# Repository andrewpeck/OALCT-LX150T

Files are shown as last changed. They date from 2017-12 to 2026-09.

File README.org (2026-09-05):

#+TITLE: ALCT Spartan-6 LX150T Mezzanine
#+OPTIONS: toc:2 num:nil

This repository holds the Altium design for the ALCT Spartan-6 LX150T
mezzanine, produced for the CSC Phase 2 Upgrade. The documentation and
design files below are archived from the CMS TWiki topic
[[https://twiki.cern.ch/twiki/bin/view/CMS/ALCTCSCPhase2Upgrade][ALCTCSCPhase2Upgrade]].

Slides from the ALCT mezzanine Production Readiness Review, held on 8 June
2018 ([[https://indico.cern.ch/event/734723/][indico]]), provide additional information:
[[file:assets/20180608_alct_mezzanines_prr.pdf][20180608_alct_mezzanines_prr.pdf]]. The committee conclusions from the review
are available here: [[file:assets/ALCT_MEZ_Review_w_append.pdf][ALCT_MEZ_Review_w_append.pdf]].

Below, Version 1 refers to prototypes, Version 2 has been used for the
production runs.

* Overview

The ALCT Spartan-6 LX150T mezzanine is designed as a replacement mezzanine
for ALCT-672 motherboards, intended to be used in ME2/1, ME3/1, and ME4/1.
It also retains compatibility for ALCT-288 and ALCT-384 motherboards, but
its use is not expected there.

Relative to the 2012 Spartan-6 mezzanine, the new LX150T mezzanine adds two
3.2 Gbps (line rate) optical links providing 5.12 Gbps of user DAQ
bandwidth to the ODMB on a CERN radiation hard VTTx.

Due to the lack of LHC synchronous (40.08 MHz) reference clock on the board
because of a scarcity of QPLL ASICs, a commercial asynchronous 80.0 MHz
oscillator is used for the MGT reference clock.

#+CAPTION: ALCT Spartan-6 LX150T mezzanine, v2 (2019-01-23)
#+ATTR_HTML: :width 600


* Documentation

- pdf: [[file:assets/ALCT_spartan-6_lx150t_specification.pdf][ALCT_spartan-6_lx150t_specification.pdf]]
- word: [[file:assets/ALCT_spartan-6_lx150t_specification.docx][ALCT_spartan-6_lx150t_specification.docx]]

* Design Files
** Version 2

- v2 2019-01-23 Vendor Files (includes Gerber, ODB, NCdrill, BOM, etc):
  - [[file:assets/ALCT_MEZ_LX150T_v2_20190123_for_fabricator.zip][ALCT_MEZ_LX150T_v2_20190123_for_fabricator.zip]]
- v2 2019-01-23 Project files (includes Altium files):
  - [[file:assets/ALCT_MEZ_LX150T_PCB_PROJECT_20190123.zip][ALCT_MEZ_LX150T_PCB_PROJECT_20190123.zip]]
- v2 2019-01-23 schematics pdf:
  - [[file:assets/ALCT_MEZ_LX150T_Schematic_Color_2019-01-23_v2.pdf][ALCT_MEZ_LX150T_Schematic_Color_2019-01-23_v2.pdf]]
- v2 2019-01-23 layout PDF:
  - [[file:assets/ALCT_MEZ_LX150T_Layout_2019-01-23_v2.pdf][ALCT_MEZ_LX150T_Layout_2019-01-23_v2.pdf]]
- v2 2019-01-23 assembly drawing:
  - [[file:assets/ALCT_MEZ_LX150T_Assembly_Top_2019-01-23_v2.pdf][ALCT_MEZ_LX150T_Assembly_Top_2019-01-23_v2.pdf]]
  - [[file:assets/ALCT_MEZ_LX150T_Assembly_Bottom_2019-01-23_v2.pdf][ALCT_MEZ_LX150T_Assembly_Bottom_2019-01-23_v2.pdf]]
- v2 2019-01-23 Bill of Materials:
  - [[file:assets/ALCT_MEZ_LX150T_BOM_2018-10-31_v2.csv][ALCT_MEZ_LX150T_BOM_2018-10-31_v2.csv]]
- UCF File:
  - [[file:assets/LX150T_v1_alct672.ucf][LX150T_v1_alct672.ucf]] (unchanged from v1)
- ODMB modified firmware for PRBS link testing (temporary, non-official,
  for testing--- new ODMB firmware can substitute for this already. please
  contact [[https://twiki.cern.ch/twiki/bin/view/CMS/UCSB][UCSB]]).
  - project: [[file:assets/odmb_alct_test.tar.gz][odmb_alct_test.tar.gz]]
  - bit: [[file:assets/odmb_ucsb_v2.bit][odmb_ucsb_v2.bit]]
  - chipscope: [[file:assets/odmb_alct_test.cpj][odmb_alct_test.cpj]]

** Version 1

- v1 2017-12-06 prototype files (includes schematic, layout, BOM, gerbers):
  - [[file:assets/LX150T_v1_20171206.tar.gz][LX150T_v1_20171206.tar.gz]]
- v1 2017-12-06 prototype schematics PDF:
  - [[file:assets/ALCT_MEZ_LX150T_Schematic_Color_2017-12-06_v1.pdf][ALCT_MEZ_LX150T_Schematic_Color_2017-12-06_v1.pdf]]
- v1 2017-12-06 layout schematics PDF:
  - [[file:assets/ALCT_MEZ_LX150T_Layout_2017-12-06_v1.pdf][ALCT_MEZ_LX150T_Layout_2017-12-06_v1.pdf]]
- v1 2017-12-06 prototype assembly drawing:
  - [[file:assets/ALCT_MEZ_LX150T_Assembly_Bottom_2017-12-06_v1.pdf][ALCT_MEZ_LX150T_Assembly_Bottom_2017-12-06_v1.pdf]]
  - [[file:assets/ALCT_MEZ_LX150T_Assembly_Top_2017-12-06_v1.pdf][ALCT_MEZ_LX150T_Assembly_Top_2017-12-06_v1.pdf]]
- UCF File:
  - [[file:assets/LX150T_v1_alct672.ucf][LX150T_v1_alct672.ucf]]

* Radiation testing

For 3000 fb^-1 of HL-LHC running, the maximum expected TID for the
ALCT-LX150T is 3 kRad.

All parts used on the ALCT-LX150T ([[file:assets/Bill_of_Materials-ALCT_MEZ_LX150T.csv][BOM]]) have been tested with TIDs equal or
greater to 30 kRad. Slides 62-64 of the ALCT talk in the ESR
([[file:assets/18-07-02_Andrew_Peck_-_alct_mezzanines_esr_v6.pdf][pdf]]) lay out the tests for each part:

- Most parts were also used in the ALCT-S6 board, installed during LS1.
  These parts were successfully tested in June 2012 at the UC Davis
  cyclotron to 30 kRad ([[file:assets/12-07-20_Jay_Hauser_-_ALCT_mezz_for_ME11-2.pdf][pdf]])
- The new XC6SLX150T FPGA is also used in the MPC and was successfully
  tested in April 2013 at the UC Davis cyclotron to 100 kRad
  ([[file:assets/13-04-01_Davis_LX150T_MPC_tests.pdf][pdf]]). MGTs were successfully tested in Jun 2018 to 15 kRad
  ([[file:assets/18-07-25_TAMU_test_Feb_2017.pdf][pdf]])
- The new oscillators (ASV-33.000MHZ-EJ-T and SG3225VAN 80.000000M-KEGA3)
  were tested in April 2018 at the Texas A&M reactor to 30 kRad
  ([[file:assets/18-07-21_TAMU_test_Mar_2018.pdf][pdf]])
- The VTTx is a radiation-hard transceiver qualified by CERN
  ([[file:assets/VTRx_Spec_v2.2.pdf][pdf]])

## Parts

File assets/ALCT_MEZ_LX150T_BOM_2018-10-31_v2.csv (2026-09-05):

Comment | Description | Designator | Footprint | LibRef | Manufacturer | Manufacturer Part Number | Quantity | Supplier 1 | Supplier Part Number 1
4.7uF | CAP CER 4.7UF 35V X5R 0603 | C1, C2, C9, C10, C88, C89, C107, C120, C121, C122, C123, C124, C125, C126, C127, C128, C129, C130, C131, C132, C134, C135, C136, C137, C138, C139, C140, C141, C142, C143, C144, C301, C311, C321, C331, C341, C351, C361, C362, C363, C364, C371, C372, C373, C374 | MC_S6/SM/C_0603_IPC | GRM188R6YA475KE15D | Murata | GRM188R6YA475KE15D | 45 | Digikey | 490-7205-1-ND
10uF | CAP CER 10UF 25V X5R 0805 | C3, C4, C6, C7, C11, C12, C14, C15, C17, C18, C29, C54, C58, C60, C65, C69, C71, C82, C90, C99, C100, C103, C110, C113, C146, C302, C312, C322, C332, C342, C365, C375 | MC_S6/SM/C_0805_IPC | GRM21BR61E106KA73L | Murata Electronics North America | GRM21BR61E106KA73L | 32 | Digi-Key | 490-5523-1-ND
0.01uF | CAP CER 10nF 16V X7R 0402 | C5, C8, C13, C16, C19, C26, C27, C84, C85, C106, C116, C133, C145, C148 | MC_S6/SM/C_0402_IPC | C0402C103K4RACTU | KEMET | C0402C103K4RACTU | 14 | Digi-Key | 399-1038-1-ND
0.47uF | CAP CER 0.47UF 10V X5R 0402 | C20, C21, C22, C23, C24, C25, C33, C40, C41, C42, C43, C44, C45, C46, C47, C78, C83, C101, C111, C119, C147, C201, C202, C203, C204, C205, C211, C212, C213, C214, C215, C221, C222, C223, C224, C225, C231, C232, C233, C234, C235, C241, C242, C243, C244, C251, C252, C253, C254, C261, C262, C263, C264, C265, C266, C267, C268, C271, C272, C273, C274, C275, C276 | MC_S6/SM/C_0402_IPC | GRM155R61A474KE15J | Murata Electronics North America | GRM155R61A474KE15J | 63 | Digi-Key | 490-6305-1-ND
0.1uF | CAP CER 0.1UF 16V X7R 0402 | C28, C30, C31, C32, C50, C51, C52, C53, C55, C56, C57, C59, C61, C62, C63, C64, C66, C67, C68, C70, C72, C73, C74, C75, C76, C77, C105, C109, C115 | MC_S6/SM/C_0402_IPC | C0402C104K4RACTU | KEMET | C0402C104K4RACTU | 29 | Digi-Key | 399-3521-1-ND
0.01uF | CAP CER 10000PF 50V NP0 0603 | C80, C81, C97, C98 | MC_S6/SM/C_0603_IPC | C0603C103J3GACTU | KEMET | C0603C103J3GACTU | 4 | Digi-Key | 399-7838-1-ND
100uF | CAP CER 100UF 10V X5R 1210 | C86, C87, C102, C112, C401, C411, C421, C431, C441, C451, C461, C462, C471, C472 | MC_S6/SM/C_1210_IPC | LMK325BJ107MM-T | Taiyo Yuden | LMK325BJ107MM-T | 14 | Digi-Key | 587-1965-1-ND
0.22uF | CAP CER 0.22UF 15V X7R 0402 | C91, C92, C93, C94, C95, C96 | MC_S6/SM/C_0402_IPC | GRM155R71C224KA12D | Murata Electronics North America | GRM155R71C224KA12D | 6 | Digi-Key | 490-5418-1-ND
0.47uF | CAP CER 0.47UF 25V X7R 0603 | C104, C108, C114, C117, C118 | MC_S6/SM/C_0603_IPC | GRM188R71E474KA12D | Murata | GRM188R71E474KA12D | 5 | Digikey | 490-3291-1-ND
220uF | CAP TANT 220UF 16V 10% 2917 | CT1, CT2, CT3, CT4, CT5, CT6, CT7, CT8, CT9, CT10, CT11, CT12, CT13 | MC_S6/SM/CT_2917_D | T491D227K016AT | KEMET | T491D227K016AT | 13 | Digi-Key | 399-10429-1-ND
LTST-C193TBKT-5A | LED BLUE CLEAR 0603 SMD | D1 | MC_S6/SM/LED_0603 | LTST-C193TBKT-5A | Lite-On Inc. | LTST-C193TBKT-5A | 1 | Digi-Key | 160-1827-1-ND
LTST-C193KGKT-5A | LED GREEN CLEAR 0603 SMD | D2 | MC_S6/SM/LED_0603 | LTST-C193KGKT-5A | Lite-On Inc. | LTST-C193KGKT-5A | 1 | Digi-Key | 160-1828-1-ND
LTST-C193KRKT-5A | LED RED CLEAR 0603 SMD | D40, D41 | MC_S6/SM/LED_0603 | LTST-C193KRKT-5A | Lite-On Inc. | LTST-C193KRKT-5A | 2 | Digi-Key | 160-1830-1-ND
VTTX | CONN FP+ CAGE 30AU SMD | J1 | MC_S6/SM/TE-1888247-1 | VTTX | TE Connectivity AMP Connectors | 1888247-1 | 1 | Digi-Key | A97943CT-ND
1uH | IND, Air Core, 1uH, 880mA, TH | L3, L4 | MC_S6/TH/DELEVAN1537 | 1537-12K | API Delevan Inc. | 1537-12K | 2 | Digi-Key | 1134-1088-1-ND
CERN VTTX | Versatile Twin Transmitter Module | PCBM1 | PCBM_CERN_VTTX V2.1 |  | CERN | VTTX-V2.1 | 1
1.2k | RES SMD 1.2K OHM 0.1% 1/16W 0402 | R1, R15 | MC_S6/SM/R_0402_IPC | ERA-2AEB122X | Panasonic Electronic Components | ERA-2AEB122X | 2 | Digi-Key | P1.2KDCCT-ND
4.7k | RES SMD 4.7K OHM 1% 1/10W 0603 | R2, R5, R8, R11, R16, R40, R43, R44, R55, R81, R82, R83, R101, R103, R104, R105, R106, R108 | MC_S6/SM/R_0603_IPC | CR0603-FX-4701ELF | Bourns Inc. | CR0603-FX-4701ELF | 18 | Digi-Key | CR0603-FX-4701ELFCT-ND
300R | RES SMD 300 OHM 0.1% 1/16W 0402 | R3, R17 | MC_S6/SM/R_0402_IPC | ERA-2AEB301X | Panasonic Electronic Components | ERA-2AEB301X | 2 | Digi-Key | P300DCCT-ND
5.1k | RES SMD 5.1K OHM 0.1% 1/16W 0402 | R4, R20, R21, R22, R23, R26, R27, R28 | MC_S6/SM/R_0402_IPC | ERA-2AEB512X | Panasonic Electronic Components | ERA-2AEB512X | 8 | Digi-Key | P5.1KDCCT-ND
1.96k | RES SMD 1.96K OHM 0.1% 1/16W 0402 | R6 | MC_S6/SM/R_0402_IPC | ERA-2AEB1961X | Panasonic Electronic Components | ERA-2AEB1961X | 1 | Digi-Key | P1.96KDCCT-ND
1.8k | RES SMD 1.8k OHM 0.1% 1/16W 0402 | R7, R10 | MC_S6/SM/R_0402_IPC | ERA-2AEB182X | Panasonic Electronic Components | ERA-2AEB182X | 2 | Digi-Key | P1.8KDCCT-ND
1.3k | RES SMD 1.3k OHM 0.1% 1/16W 0402 | R9, R12 | MC_S6/SM/R_0402_IPC | ERA-2AEB132X | Panasonic Electronic Components | ERA-2AEB132X | 2 | Digi-Key | P1.3KDCCT-ND
110R | RES SMD 110 OHM 1% 1/10W 0402 | R13, R14, R56, R57 | MC_S6/SM/R_0402_IPC | ERJ-2RKF1100X | Panasonic Electronic Components | ERJ-2RKF1100X | 4 | Digi-Key | P110LCT-ND
768R | RES SMD 768 OHM 5.0% 1/10W 0402 | R24, R25 | MC_S6/SM/R_0402_IPC | ERJ-2RKF7680X | Panasonic Electronic Components | ERJ-2RKF7680X | 2 | Digi-Key | P768LCT-ND
10M | RES SMD 10M OHM 5% 1/10W 0402 | R41, R48, R49, R54 | MC_S6/SM/C_0402_IPC | ERJ-2GEJ106X | Panasonic Electronic Components | ERJ-2GEJ106X | 4 | Digi-Key | P10MJCT-ND
330R | RES SMD 330 OHM 1% 1/10W 0603 | R42, R107 | MC_S6/SM/R_0603_IPC | CR0603-FX-3300ELF | Bourns Inc. | CR0603-FX-3300ELF | 2 | Digi-Key | CR0603-FX-3300ELFCT-ND
510R | RES SMD 510 OHM 1% 1/10W 0603 | R45, R58, R59 | MC_S6/SM/R_0603_IPC | CR0603-FX-5100ELF | Bourns Inc. | CR0603-FX-5100ELF | 3 | Digi-Key | CR0603-FX-5100ELFDKR-ND
28R | RES SMD 28 OHM 1% 1/10W 0603 | R46 | MC_S6/SM/R_0603_IPC | ERJ-3EKF28R0V | Panasonic Electronic Components | ERJ-3EKF28R0V | 1 | Digi-Key | P28.0HCT-ND
0.0R | RES SMD 0.0OHM JUMPER 1/10W 0402 | R50, R51, R52, R53 | MC_S6/SM/R_0402_IPC | ERJ-2GE0R00X | Panasonic Electronic Components | ERJ-2GE0R00X | 4 | Digi-Key | P0.0JCT-ND
49.9R | RES SMD 49.9 OHM 0.1% 1/8W 0805 | R80 | MC_S6/SM/R_0805_IPC | ERA-6AEB49R9V | Panasonic Electronic Components | ERA-6AEB49R9V | 1 | Digi-Key | P49.9DACT-ND
187R | RES SMD 187 OHM 1% 1/10W 0603 | R100, R102 | MC_S6/SM/R_0603_IPC | ERJ-3EKF1870V | Panasonic Electronic Components | ERJ-3EKF1870V | 2 | Digi-Key | P187HCT-ND
XC6SLX150T-3FGG900C | Spartan-6 LXT 1.2V FPGA, 540 User I/Os, 900-Ball Chip-Scale BGA (1.0mm Pitch), Speed Grade 3, Commercial Grade, Pb-Free | U1 | MC_S6/BGA/FGG900 | XC6SLX150T-3FGG900C | Xilinx Inc. | XC6SLX150T-3FGG900C | 1 | Digi-Key | XC6SLX150T-3FGG900C-ND
XCF32PVOG48C | IC PROM SRL/PAR 1.8V 32M 48TSOP | U2 | MC_S6/SM/VOG48 | XCF32PVOG48C | Xilinx Inc. | XCF32PVOG48C | 1 | Digi-Key | 122-1458-ND
XCF08PVOG48C | IC PROM SRL/PAR 1.8V 08M 48TSOP | U3 | MC_S6/SM/VOG48 | XCF08PVOG48C | Xilinx Inc. | XCF08PVOG48C | 1 | Digi-Key | 122-1454-ND
74LVC161PW,118 | IC SYNC 4BIT BIN COUNTER 16TSSOP | U4 | MC_S6/SM/TSSOP16 | 74LVC161PW | NXP USA Inc. | 74LVC161PW,118 | 1 | Digi-Key | 568-7667-1-ND
DS1233AZ-10+ | IC POR 2.88V 10% SOT223 | U5 | MC_S6/SM/SOT223_1243 | DS1233AZ-10+ | Maxim Integrated | DS1233AZ-10+T&R | 1 | Digi-Key | DS1233AZ-10+CT-ND
SN74LVC1G07-EP | IC BUFF/DVR NON-INVERT Open Drain SC70-5 | U6, U100 | MC_S6/SM/SOT_SC70_DCK5 | SN74LVC1G07-EP | Texas Instruments | SN74LVC1G07MDCKREP | 2 | Digi-Key | 296-22343-1-ND
SN74LVC1T45DCKR | IC BUS TRANSCVR TRI-ST SC70-6 | U7, U8, U9, U10 | MC_S6/SM/SOT_SC70_DCK6 | SN74LVC1T45-EP-ALCT_1 | Texas Instruments | SN74LVC1T45DCKR | 4 | Digi-Key | 296-16844-1-ND
DS2401Z | IC Digital Serial Number | U11 | MC_S6/SM/SOT223_1243 | DS2401_sot223 | Maxim Integrated | DS2401Z+T&R | 1 | Digi-Key | DS2401Z+T&RCT-ND
MIC69502WR | IC REG LDO ADJ 5A SPAK-7 | U12, U13, U14, U20, U21 | MC_S6/SM/SPAK7 | MIC69502WR | Microchip Technology | MIC69502WR | 5 | Digi-Key | 576-1613-ND
TLV2543CDB | IC SERIAL OUT A/D 11-CH 20-SSOP | U15 | MC_S6/SM/ADC_DB20 | TLV2543CDB | Texas Instruments | TLV2543CDBR | 1 | Digi-Key | 296-10643-1-ND
LT1634ACS8-2.5 | IC VREF SHUNT 2.5V 8SOIC | U16 | MC_S6/SM/LT1634_SOIC8 | LT1634_2.5V | Linear Technology | LT1634ACS8-2.5#PBF | 1 | Digi-Key | LT1634ACS8-2.5#PBF-ND
SN74LVC1G34 | IC BUFFER NON-INVERT SOT5 | U17 | MC_S6/SM/SOT_553_DRL5 | SN74LVC1G34DRLR | Texas Instruments | SN74LVC1G34DRLR | 1 | Digi-Key | 296-18017-1-ND
TMP36GRTZ | SENSOR TEMP ANLG VOLT SOT-23-5 | U18, U19 | MC_S6/SM/SOT23_RJ5 | TMP36GRTZ | Analog Devices | TMP36GRTZ-REEL7 | 2 | Digi-Key | TMP36GRTZ-REEL7CT-ND
74AUP1G04GW | IC INVERTER LP 5TSSOP | U40 | SOT353-1 | 74AUP1G04GW | Nexperia USA Inc. | 74AUP1G04GW,125 | 1 | Digi-Key | 1727-3176-1-ND
DS90LV047ATMTCX/NOPB | IC LINE DVR 3V QUAD DIFF 16TSSOP | U80 | MC_S6/SM/TSSOP16 | DS90LV047ATMTCX | TI National Semiconductor | DS90LV047ATMTCX/NOPB | 1 | Digi-Key | DS90LV047ATMTCX/NOPBDKR-ND
74LVC2T45DC,125 | IC TRNSLTR BIDIRECTIONAL 8VSSOP | U101 | VSSOP8 SOT765-1 | 74LVC2T45DC,125 | Nexperia USA Inc. | 74LVC2T45DC,125 | 1 | Digi-Key | 1727-4578-6-ND
SG3225VAN 80.000000M-KEGA3 | OSC 80.0000MHZ LVDS SMD | X1 | MC_S6/SM/XTAL-LVDS-3.2-2.5 | SG3225VAN 80.000000M-KEGA3 | EPSON | SG3225VAN 80.000000M-KEGA3 | 1 | Digi-Key | SER3935CT-ND
ASV-33.000MHZ-EJ-T | XTAL, 33MHz, CMOS | X2 | MC_S6/SM/XTAL-7x5.08 | ASV-33.000MHZ-EJ-T | Abracon LLC | ASV-33.000MHZ-EJ-T | 1 | Digi-Key | 535-9324-6-ND
CFPS-73 80.0 MHz | XTAL, 80MHz, CMOS | X3 | MC_S6/SM/XTAL-7x5.08 | LFSPXO009441 | IQD | LFSPXO009441REEL | 1 | Digi-Key | 1923-1130-6-ND
Samtec_XP1 |  | XP1 | MC_S6/TH/SAMTEC_MOLC_40x4 | Samtec_XP1 | SAMTEC | MOLC-140-01-L-Q-LC | 1 | Farnell | 2732055
Samtec_XP2 |  | XP2 | MC_S6/TH/SAMTEC_MOLC_40x4 | Samtec_XP2 | SAMTEC | MOLC-140-01-L-Q-LC | 1 | Farnell | 2732055
Samtec_XP3 |  | XP3 | MC_S6/TH/SAMTEC_MOLC_40x4 | Samtec_XP3 | SAMTEC | MOLC-140-01-L-Q-LC | 1 | Farnell | 2732055
Samtec_XP4 |  | XP4 | MC_S6/TH/SAMTEC_MOLC_40x4 | Samtec_XP4 | SAMTEC | MOLC-140-01-L-Q-LC | 1 | Farnell | 2732055

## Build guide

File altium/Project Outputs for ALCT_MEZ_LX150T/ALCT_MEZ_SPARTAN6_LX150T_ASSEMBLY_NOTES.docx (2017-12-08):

December 6, 2017

## UCLA MC S6 LX150T rev 1 Assembly Information

## XP1-XP4: Connectors must be seated flatly against the PCB, no tilting allowed

a) These connectors must mate precisely with off-board objects and must be installed flatly against the PCB to ensure alignment.
b) Care should be taken during soldering to minimize board work

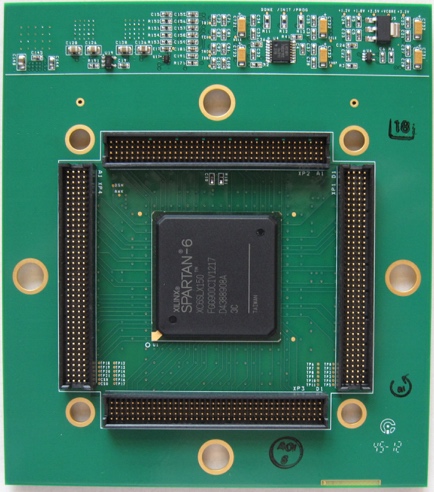
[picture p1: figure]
mc_s6_rev1_bot

Connectors seated flatly

against PCB, no tilting

Keep contact pins clean

## Screw holes will be used for mounting and should be kept clean

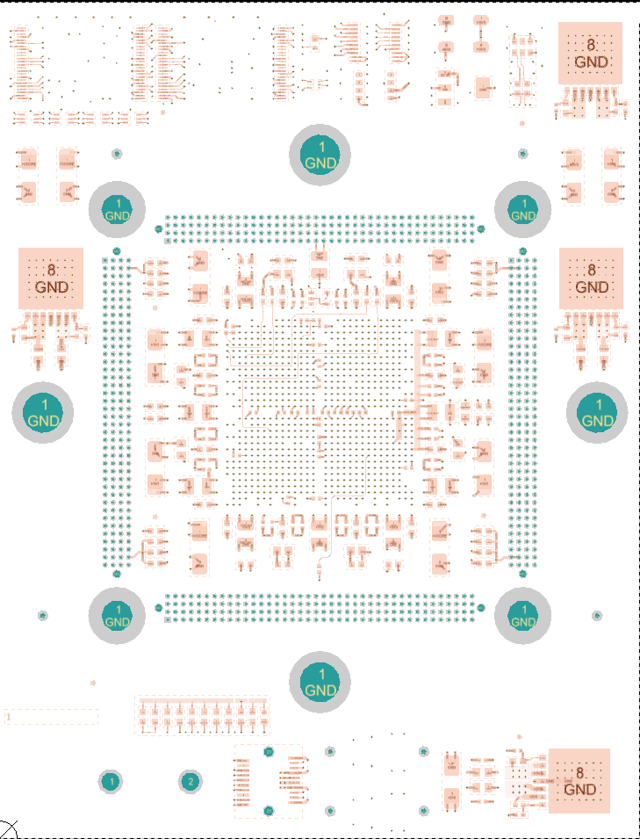
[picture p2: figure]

Keep screw holes clear

## Shipping

a) Please pack assembled boards carefully
b) Show the UCLA PO number on the packing list
c) Ship Fedex ground prepaid to

UCLA Physics Department

Knudsen Hall 1-129

475 Portola Plaza

Los Angeles, CA 90095-1547

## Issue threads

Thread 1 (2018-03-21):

BOM discrepancy

andrewpeck, 2018-03-21:
Description column called out "SOT-23-5" but as per Manufacturer Part Number(TMP36FSZ-REEL) is SOIC-8. At present we have followed Manufacturer Part Number column(SOIC-8). Please confirm
* This should, in fact, be SOT-23-5, P/N TMP36GRTZ. There was a transcription mistake. I will update this in the BOM    

For p/n C0603C103J3GACTU there is Voltage mismatch between Description column(50V) & Manufacturer Part Numbercolumn(25V). At present we have followed Manufacturer Part Number column(25V). Please confirm
* 25V of the manufacturer is fine.  I will correct the description.

Closed 2021-05-25.

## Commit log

2017-08-27 Init to git
    [ADC.SchDoc, ALCT2017_Logic.SchDoc, ALCT_MEZ_SPARTAN6.PrjPcb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]
2017-10-17 Addition of optional configuration crystal; changes to project name
    [ALCT_MEZ_LX150T.PrjPcb, Configuration_Logic.SchDoc, Configuration_Power.SchDoc]
2017-10-18 Conversion back to binary SchDocs. Replace all regulators with MIC69502WR & update layout. Widen outer layer traces. Remove outer layer planes
    [ADC.SchDoc, ALCT2017_Logic.SchDoc, Configuration_Logic.SchDoc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]
2017-10-18 Change sheet background color. Update symbol for CERN VTTX PCB Mount to match document theme
    [ADC.SchDoc, ALCT2017_Logic.SchDoc, Configuration_Logic.SchDoc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]
2017-10-31 Split VCCAUX to 2.5V; update layout
    [ADC.SchDoc, Configuration_Logic.SchDoc, Configuration_Power.SchDoc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]
2017-11-02 Reroute differential pairs with new stackup report
    [ALCT2017_Logic.SchDoc, FPGA_Power.SchDoc, Power.SchDoc]
2017-12-11 Very minor corrections to graphical elements of samtec connectors (no netlist change)
    [Connectors.SchDoc]
2017-12-11 Move fabrication and assembly notes
    [ALCT_MEZ_LX150T.PrjPcb]
2018-02-22 Minor tweaks to graphical elements of schematics (page titles)
    [ADC.SchDoc, ALCT2017_Logic.SchDoc, ALCT_MEZ_LX150T.PrjPcb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]
2018-08-07 Update revision and date on schematics
    [ADC.SchDoc, ALCT2017_Logic.SchDoc, Configuration_Logic.SchDoc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]
2018-08-07 Initial routed version of v2 board
    [ADC.SchDoc, ALCT2017_Logic.SchDoc, ALCT_MEZ_LX150T.PrjPcb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]
2018-08-07 Updates to BOM parameters of a couple items
    [Configuration_Logic.SchDoc, MGT.SchDoc]
2018-08-08 Cleanup assembly diagrams
2018-08-21 Addition of VTTX heatsink
    [ADC.SchDoc, ALCT2017_Logic.SchDoc, Configuration_Logic.SchDoc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]
2018-10-31 Correct temperature sensor part number in BOM
    [ADC.SchDoc, ALCT_MEZ_LX150T.PrjPcb]
2019-01-22 Additions of IPC netlist and assembly layers to output job
2026-09-05 add readme and artifacts
    [ALCT_MEZ_LX150T_BOM_2018-10-31_v2.csv, Bill_of_Materials-ALCT_MEZ_LX150T.csv]
2026-09-05 move altium into altium dir
    [ADC.SchDoc, ALCT2017_Logic.SchDoc, ALCT_MEZ_LX150T.PcbDoc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]
